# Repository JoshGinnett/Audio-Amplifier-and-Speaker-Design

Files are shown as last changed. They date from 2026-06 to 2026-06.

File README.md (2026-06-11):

# Audio Amplifier and Speaker System - ECE4095

A battery-powered audio amplifier and speaker system with selectable aux and optical inputs, dual laser transmitter outputs, and a fully custom PCB. Designed as part of ECE 4095 at the University of Connecticut.

## Product Photos

| Front Panel | Rear / Speaker | Interior |
|---|---|---|
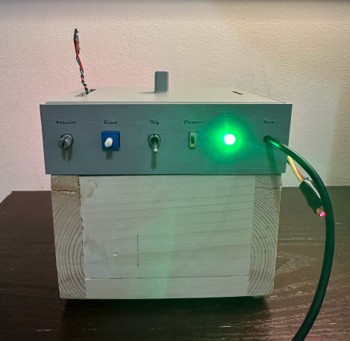
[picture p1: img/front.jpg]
Front
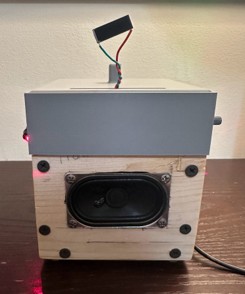
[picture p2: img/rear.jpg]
Rear
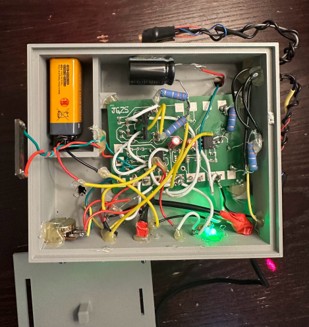
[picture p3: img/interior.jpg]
Interior
|  |  |  |

## Features

- Selectable **aux or optical (solar cell) input** via front-panel switch
- **Solar cell preamp stage** with high-pass filtering to match the weaker optical signal to aux levels
- Inverting **op-amp gain stage** with adjustable gain and volume potentiometers
- **Diode-biased BJT push-pull output stage** delivering ~2.5W peak into an 8Ω speaker with reduced crossover distortion
- **Dual laser transmitter outputs** with voltage follower isolation and DC-biased summing amplifier for optical audio transmission
- 9V battery powered with front-panel power switch and LED status indicator
- Custom PCB designed in **Altium Designer**, simulated in **LTspice**, enclosure modeled in **Fusion 360**

---

## System Design

### Input Stage
The aux input and solar cell photodetector are routed through a front-panel switch. Because the solar cell output (~0.35 Vrms) is significantly weaker than the aux input (~0.99 Vrms), a dedicated preamp stage boosts the optical signal before the main amplifier. A high-pass filter follows the preamp to reduce low-frequency noise from the solar cell.

### Main Amplifier
The main amplifier uses an op-amp in an inverting topology with a potentiometer in the feedback path for adjustable gain. A 10kΩ volume potentiometer at the input bleeds signal to ground for output level control. Because the op-amp alone cannot supply sufficient current to drive the speaker, a diode-biased BJT push-pull output stage provides the needed current gain. Diode biasing of the transistor pair reduces crossover distortion while keeping quiescent current low (~2 mA) for efficiency.

### Laser Output Stage
The selected input is buffered through a voltage follower for isolation, then fed into a non-inverting summing amplifier that introduces a DC bias required for laser diode modulation. Both laser outputs share this stage but are driven through separate current-limiting resistor paths.

## [Design Review Video](https://youtu.be/YMSiEr61HQ0)

---

## Hardware Summary

| Block | Details |
|---|---|
| Power | 9V battery, front-panel power switch, LED indicator |
| Input Selection | SPDT switch (aux / solar cell) |
| Solar Cell Preamp | Op-amp gain stage with high-pass filter |
| Main Amplifier | Inverting op-amp + diode-biased BJT push-pull output |
| Speaker Output | ~2.5W peak into 8Ω |
| Laser Outputs | 2× laser diodes with isolated op-amp drive paths |

---

## Repository Structure

```
├── ltspice/       # LTspice simulation files (.asc)
├── altium/        # Altium Designer schematic and PCB project files
├── fusion360/     # Fusion 360 enclosure design files
└── img/           # Project photos
└── pdf            # Project presentation
```

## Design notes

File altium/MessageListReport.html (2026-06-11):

Altium customize

# Message List

Date: | | 10/30/2025
Time: | | 6:04:37 PM
Elapsed Time: | | 00:00:00

Class | Document | Source | Message | Time | Date | No.
Update From PCB Libraries | C:\Users\joshg\OneDrive\Academia\UCONN\Courses\ECE 4095\Project 1\altium\ECE4095- Project 1- Speaker - V2\Main_Schematic.SchDoc | Update From PCB Libraries | Unprocessed component : Q1 not found on PCB. | 6:03:45 PM | 10/30/2025 | 1
[Extra Components] | Main_Schematic.SchDoc | Comparator | [Q1] in Main_Schematic.SchDoc | 6:03:51 PM | 10/30/2025 | 2

Back to top

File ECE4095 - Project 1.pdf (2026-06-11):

# Project 1

Josh Ginnett and Zach Santiana

## System Level Design Choices

Selectable Input Source: A dedicated switch allows the user to choose between aux input or the solar-cell photodetector as the signal source. This enables both direct wired playback and optical signal transmission from another student’s laser setup.

Adjustable Gain and Volume: Independent controls for amplifier gain (can be used to boost volume or add distortion if desired) and output volume.

Integrated Power System: Powered by a 9V battery with a built-in power switch and an LED status indicator, allowing the battery to remain connected without draining while providing clear visual feedback when the device is active.

Dual Laser Outputs With Dedicated Amplifier Paths: Two laser transmitters, each driven by its own amplifier stage, allow optical transmission of the audio signal with minimal added gain or noise. Using separate amplifier paths isolates the transmit channels and ensures cleaner modulation onto the laser diodes.

## Circuit Design Overview

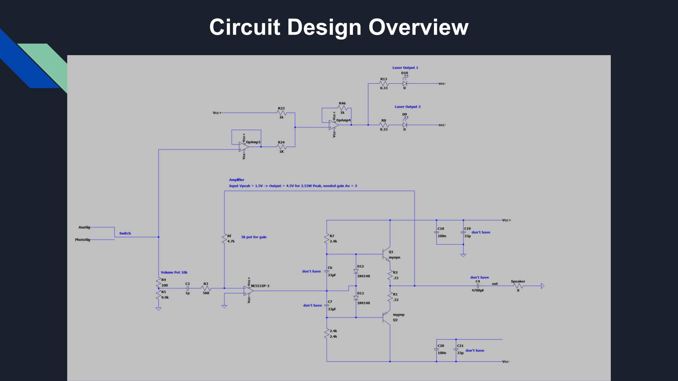
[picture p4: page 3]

## Preamp for Solar Cell

Measurements showed the aux input at approximately 0.989 Vrms, while the solar-cell output was only about 0.353 Vrms. Because the optical signal is significantly weaker, a preamplifier was required to raise the solar-cell signal to a comparable level before feeding it into the main amplifier. A high pass filter is implemented after pre amplifying to reduce signal noise from the solar cell.

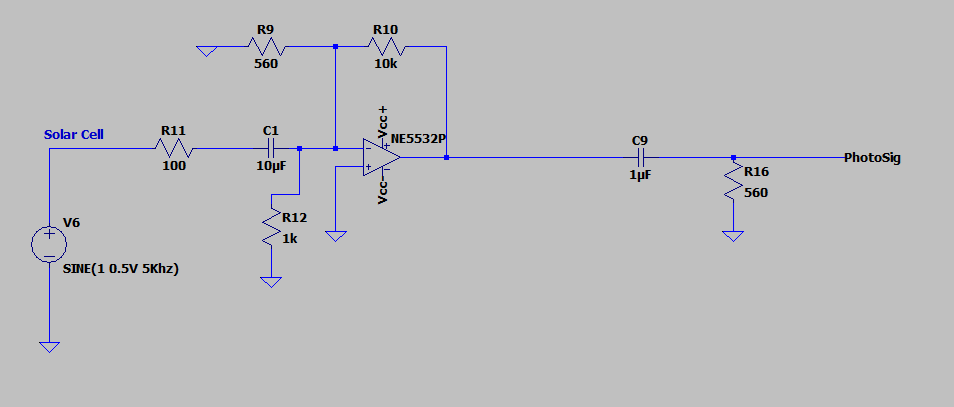
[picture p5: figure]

## Laser Output Stage

The selected input signal is first buffered with a voltage follower for isolation, then passed into a noninverting summing amplifier to introduce the required DC bias for laser modulation.

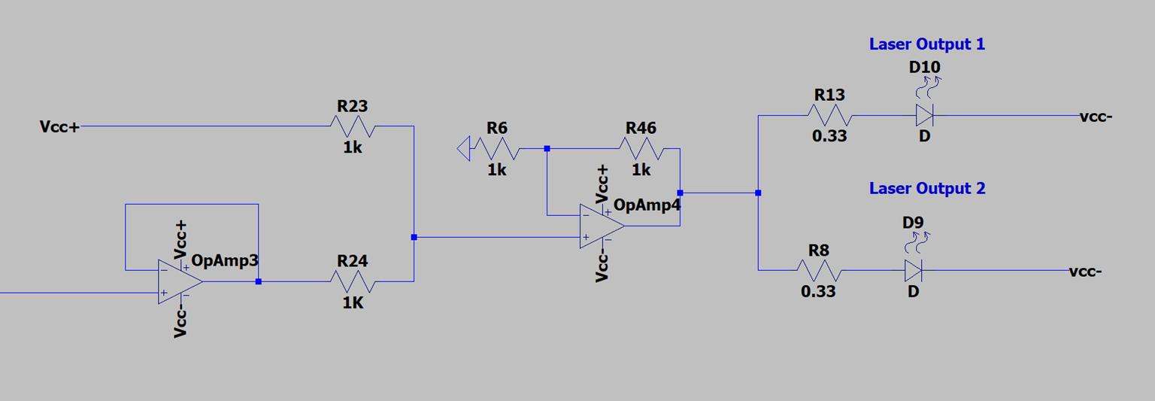
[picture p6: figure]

## Main Amplifier

The amplifier uses an NE5532P op-amp configured in an inverting topology, with a 10 kΩ potentiometer in the feedback path to provide adjustable gain. Although the NE5532P can source up to about 70 mA, this is not sufficient to drive the speaker at the required power level. To supply the needed current, a diode-biased push-pull output stage is added, providing unity voltage gain but substantial current gain. The 1N4148 diodes bias the BD139/BD140 transistor pair, reducing crossover distortion while keeping the quiescent current low (~0.2 mA) for improved efficiency.

The main amplifier is fed by the input selector switch and a 10 kΩ volume potentiometer connected to ground. This allows the user to control volume by bleeding part of the signal to ground when the potentiometer is set to lower resistance.

## Main Amplifier

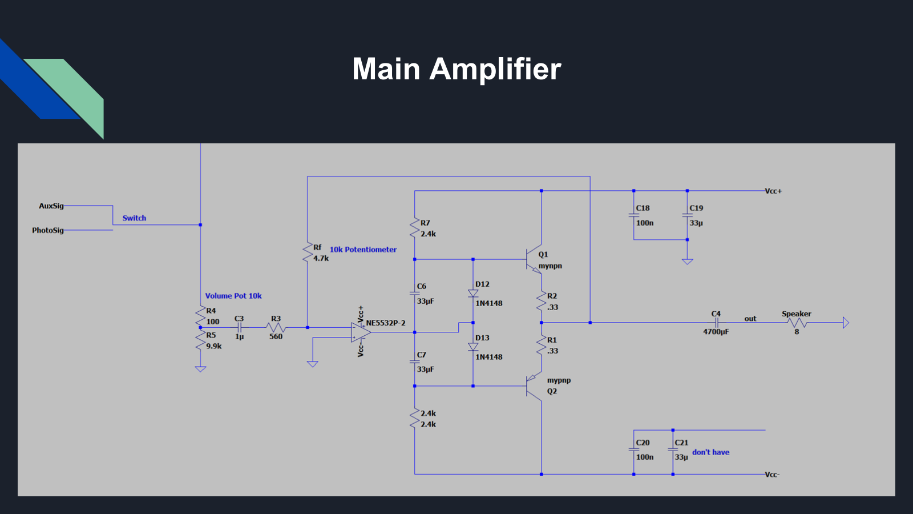
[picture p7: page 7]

## LT Spice Simulations

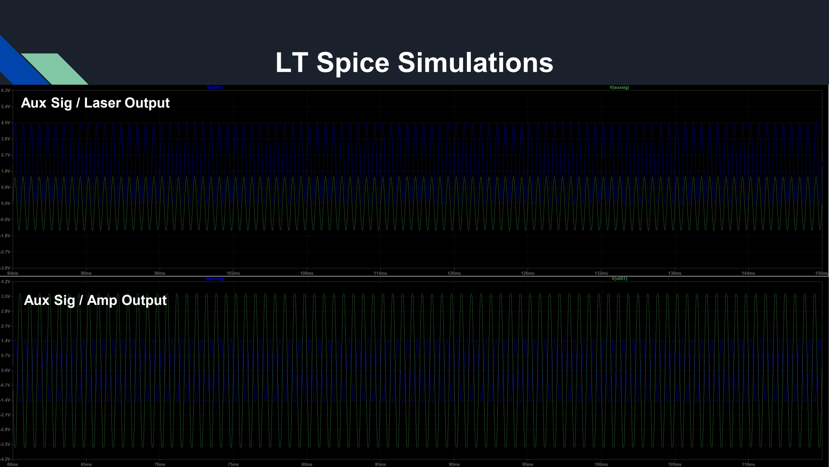
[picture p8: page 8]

Aux Sig / Amp Output

Aux Sig / Laser Output

## Altium Schematic

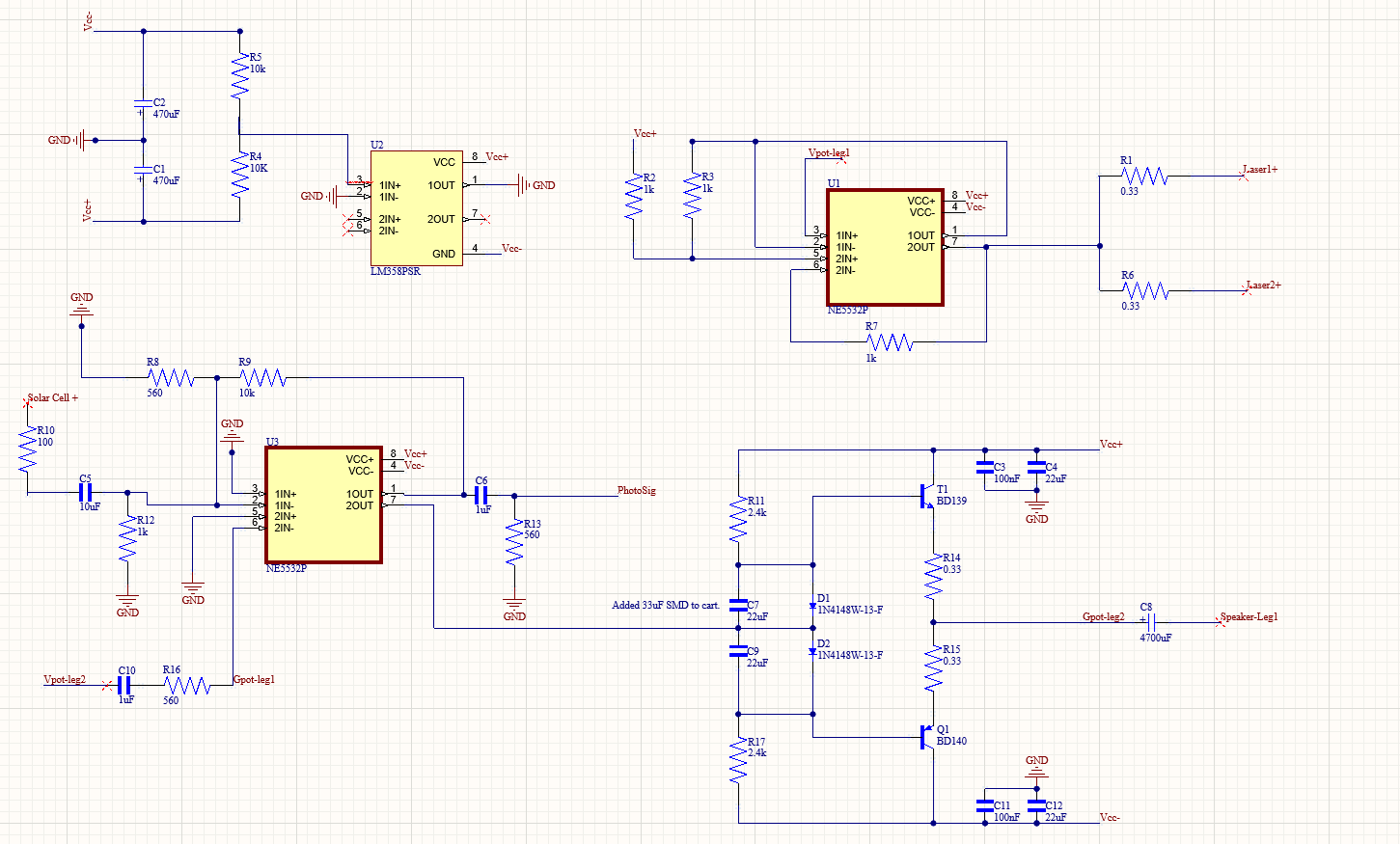
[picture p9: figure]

## Altium PCB Layout

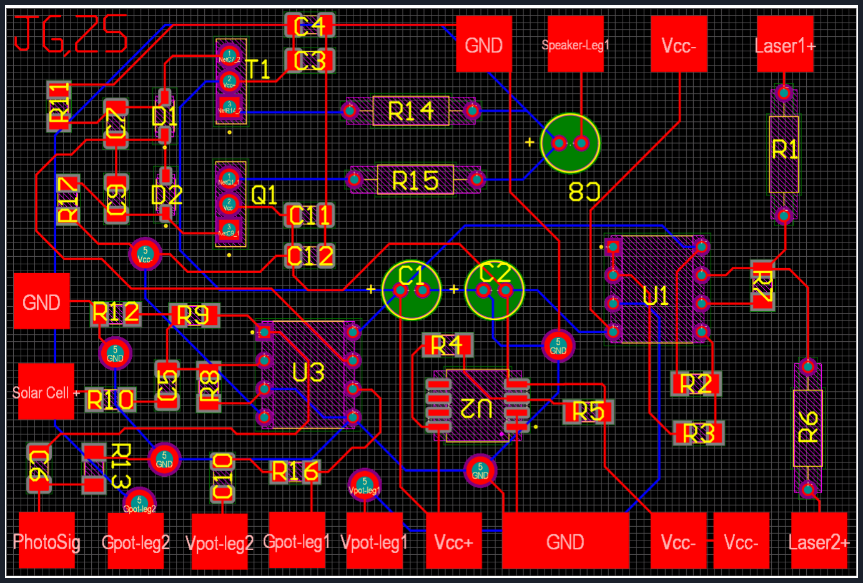
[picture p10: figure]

- Decoupling Capacitors placed as close as possible to power pins.
- Large pads used to make
soldering easy.
- Included multiple ground vias for testing / probing.
- Used minimal through-hole components.

## 3D View

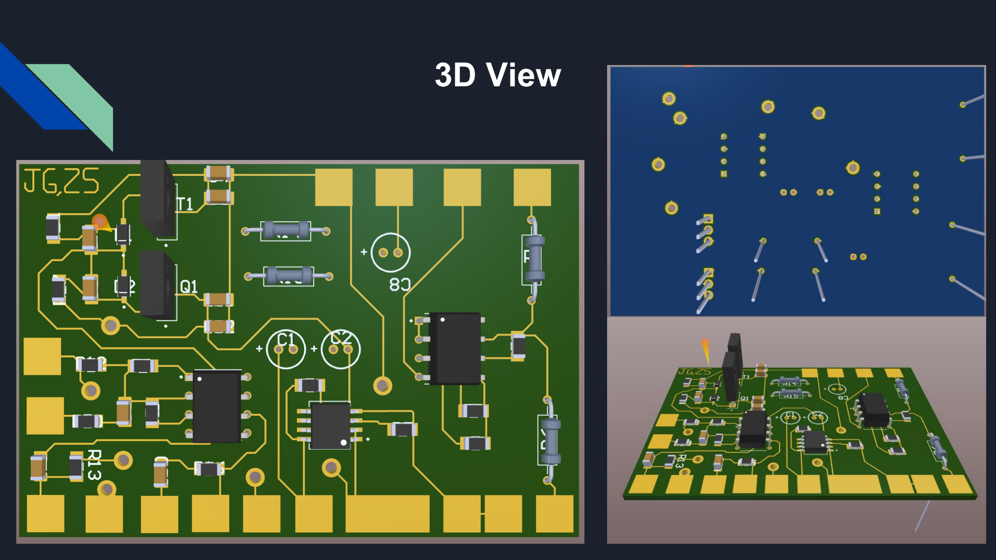
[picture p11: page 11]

## Assembled Project

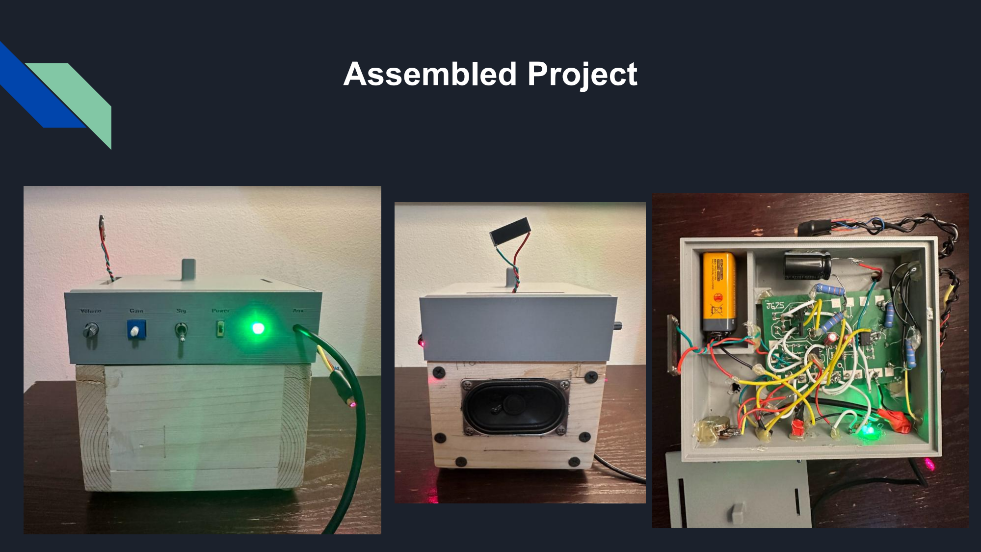
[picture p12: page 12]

## Video Demonstration

https://www.youtube.com/watch?v=YMSiEr61HQ0

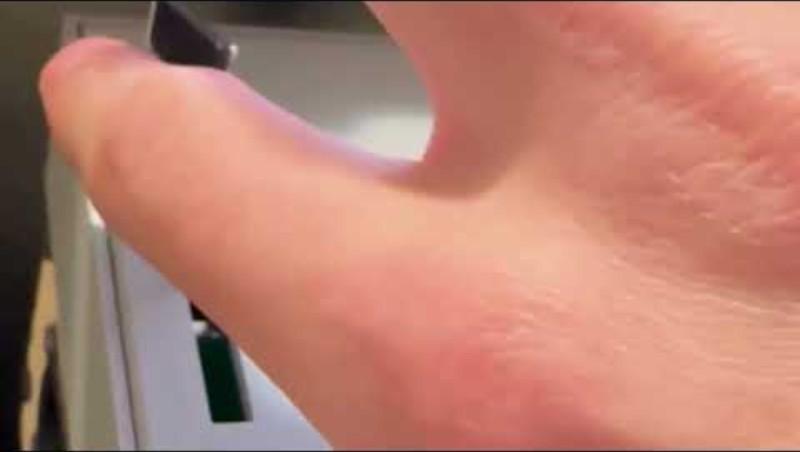
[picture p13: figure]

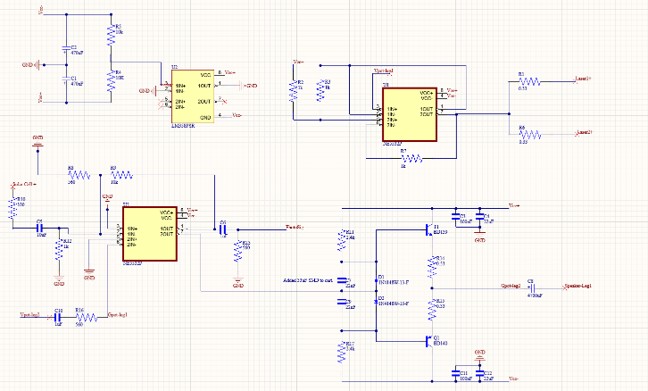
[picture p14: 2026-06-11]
img/altium_1.jpg

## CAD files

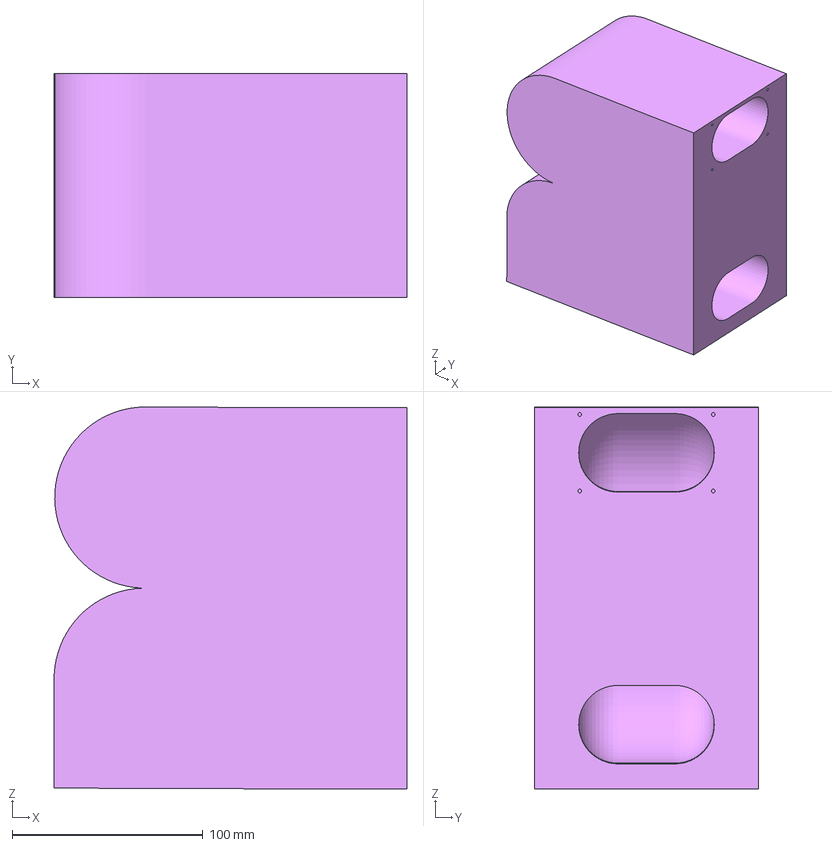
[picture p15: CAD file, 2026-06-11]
fusion360/Speaker Enclosure.3mf
184.8 x 117.1 x 200.0 mm

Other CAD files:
fusion360/Speaker Enclosure.f3d
